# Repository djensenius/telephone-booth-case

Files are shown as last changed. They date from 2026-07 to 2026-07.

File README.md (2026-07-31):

# Telephone Booth Case

A parametric, 3D-printable enclosure for the [Telephone-Booth](https://github.com/djensenius/Telephone-Booth)
art project. It is a two-bay, screw-down (M3 corner-post) case that houses:

- **Back bay** — Raspberry Pi 4B + 52Pi GPIO Screw Terminal HAT, with a Noctua
  NF-A4x20 fan mounted on the lid.
- **Front bay** — GL.iNet MUDI 7 (GL-E5800) travel router, lying flat screen-up in
  a cradle so the screen shows through the lid window. The cradle rests on tapered
  support pillars that reduce print stringing.

Internal wiring runs between the bays through the central divider, which is left
open on the router's left end so the router's ethernet door can swing open and the
power cable can reach the Pi. Power path: external USB-C inlet → router power in;
the router's USB-out feeds the Pi via a right-angle USB dongle (the reason the
router bay has extra room on that end). Two panel RJ45 keystones wire to the 52Pi
HAT (GPIO).

Current embossed versions: base **v.0.7**, lid **v.0.7.1**

## Components

Parts the case is designed around (official product pages where available, Amazon
otherwise). Panel-cutout dimensions are matched by measurement to the specific
parts linked below — swapping a part may require adjusting the model.

| Component | Where it goes | Cutout | Link |
| --- | --- | --- | --- |
| Raspberry Pi 4 Model B | Back bay | 58 × 49 mm hole pattern | [raspberrypi.com](https://www.raspberrypi.com/products/raspberry-pi-4-model-b/) |
| 52Pi GPIO Screw Terminal HAT (EP-01129) | On the Pi | — | [52pi.com](https://52pi.com/products/52pi-gpio-screw-terminal-hat-for-raspberry-pi) |
| GL.iNet MUDI 7 (GL-E5800) 5G travel router | Front bay | cradle | [gl-inet.com](https://www.gl-inet.com/products/gl-e5800/) |
| Noctua NF-A4x20 40 mm fan | Lid | ⌀37 mm grille, 32 mm screws | [noctua.at](https://noctua.at/en/nf-a4x20-flx) |
| Round USB 3.0 panel-mount bulkhead, 86-type (×2) | Back wall (→ Pi USB-A) | ⌀22.6 mm round | [Amazon.ca](https://www.amazon.ca/dp/B0F2MW7XXZ) |
| USB-C 3.1 panel-mount coupler | Router-bay right wall (power inlet) | 13 × 8 mm, 23.5 mm screws | [Amazon.ca](https://www.amazon.ca/dp/B0GF22WM9T) |
| HDMI female → micro-HDMI screw-fixing panel-mount bulkhead | Right wall (→ Pi micro-HDMI) | ⌀23 mm round, M22×1.5 nut | [Amazon.ca](https://www.amazon.ca/dp/B0BRFS28JM) |
| RJ45 CAT6 keystone panel-mount (×2, GPIO) | Left wall | 16.5 × 13.1 mm, 24.5 mm screws | [Amazon.ca](https://www.amazon.ca/dp/B071FNHVXN) |
| Rugged metal RGB pushbutton, 16 mm (Pi power) | Right wall | ⌀16 mm round | [adafruit.com](https://www.adafruit.com/product/3350) |
| Right-angle USB-A → USB-A cable, 30 cm | Router USB-out → Pi power | — (internal) | — |

Fasteners: M2.5 screws for the Pi standoffs (driven up from the underside); the
Noctua fan ships with its own self-tapping screws.

## Parts (printed)

| File | Part | Description |
| --- | --- | --- |
| [`telephone-booth-case.scad`](telephone-booth-case.scad) | Source | Parametric OpenSCAD model (all dimensions live here) |
| [`base.stl`](base.stl) | Base | Two-bay body with standoffs, cradle + tapered supports, panel cutouts and vents |
| [`lid.stl`](lid.stl) | Lid | Snap-fit lid with fan grille and router screen window |

Outer size: **250 × 250 × 73.2 mm** (base 70.8 mm + 2.4 mm lid; lid screw posts
included). The Pi-bay panel cutouts (USB, HDMI, power button, both RJ45 keystones)
are centred on the assembled box height, and the USB audio adapter cradle sits
under the HDMI bulkhead. Both parts are embossed with the version,
author (David Jensenius) and contact (david@jensenius.com).

## Previews

| Preview | View |
| --- | --- |
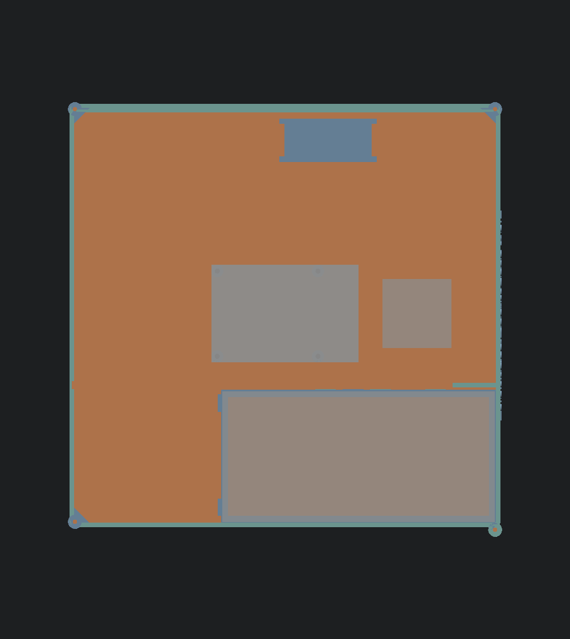
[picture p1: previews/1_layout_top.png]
Top layout
|  | Top-down layout with router + Pi ghosts |
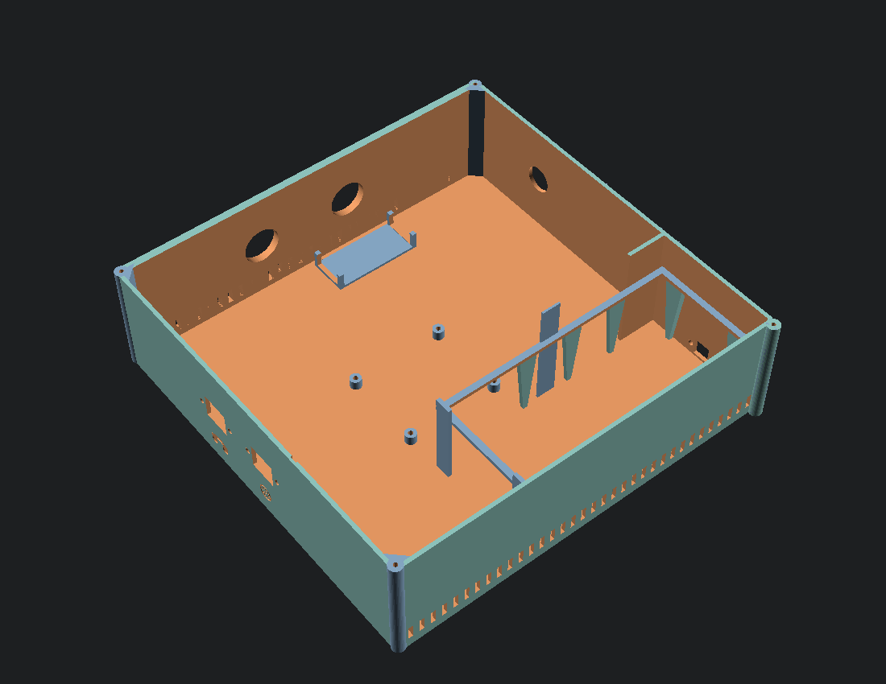
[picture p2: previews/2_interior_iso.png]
Interior
|  | Interior, both bays |
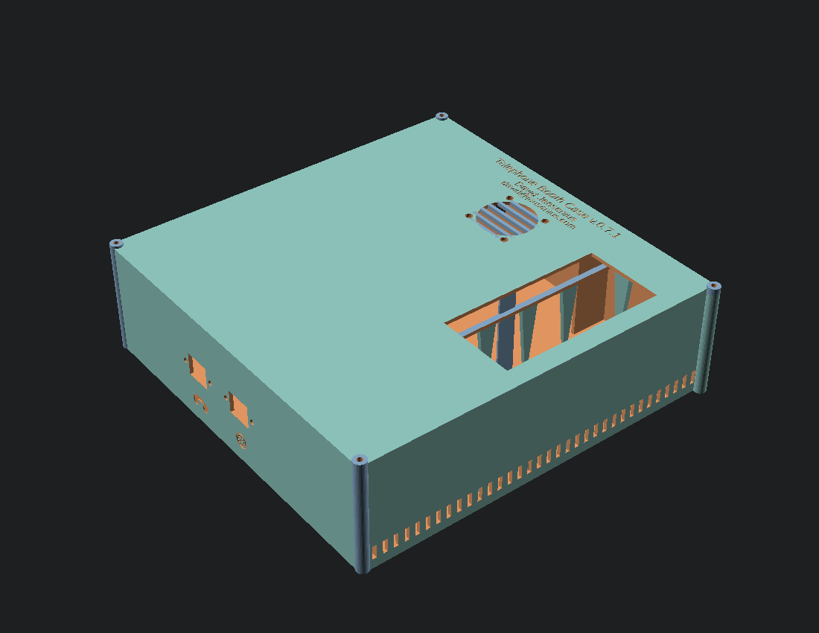
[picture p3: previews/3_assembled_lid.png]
Assembled lid
|  | Assembled — fan grille + screen window |
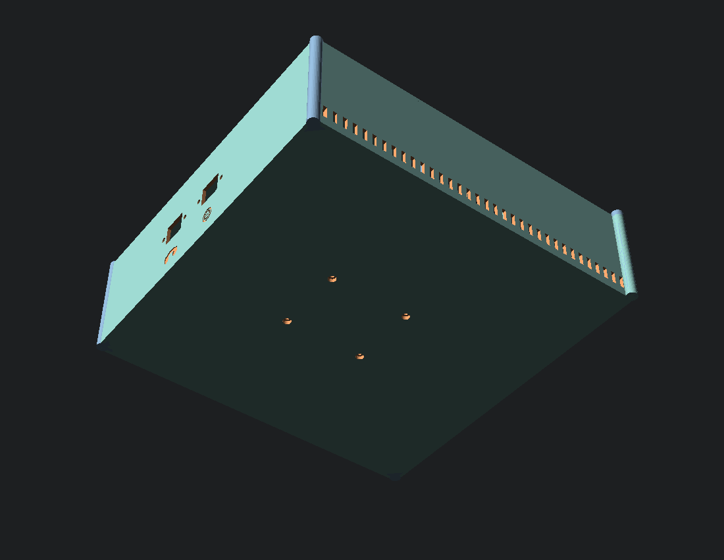
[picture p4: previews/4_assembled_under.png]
Underside
|  | Assembled underside |
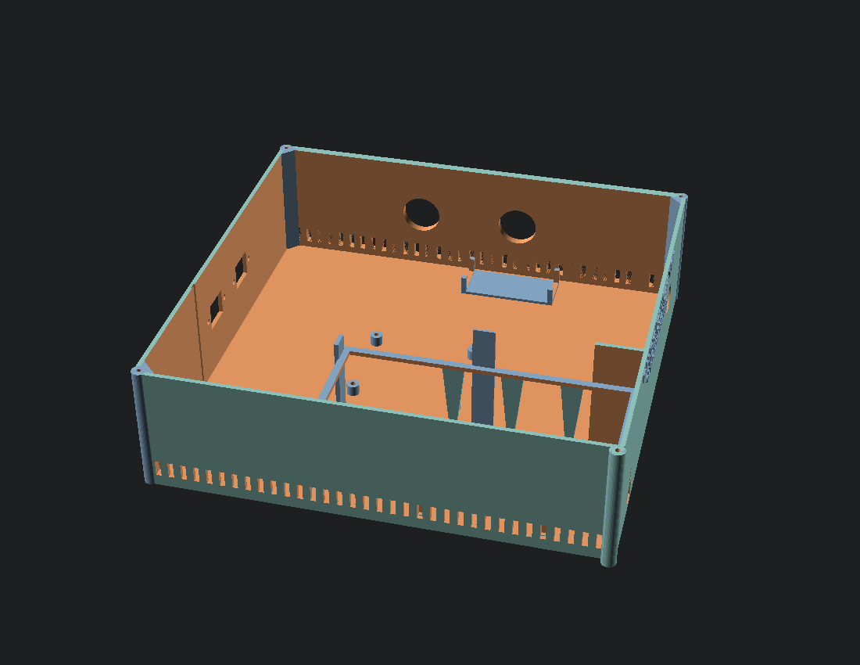
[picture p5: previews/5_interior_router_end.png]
Interior router end
|  | Interior from the router (USB-C) end — cradle supports |
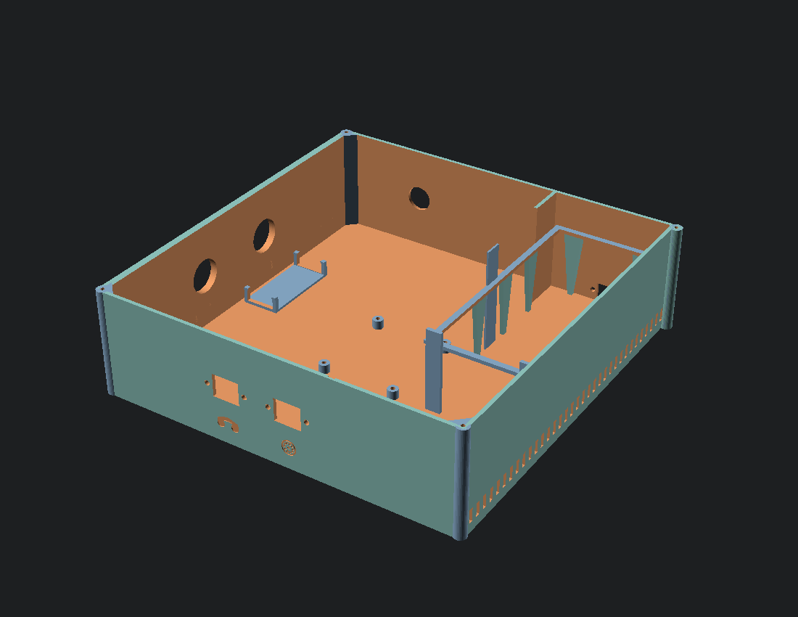
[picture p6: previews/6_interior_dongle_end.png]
Interior dongle end
|  | Interior from the dongle end — divider opened for cabling |
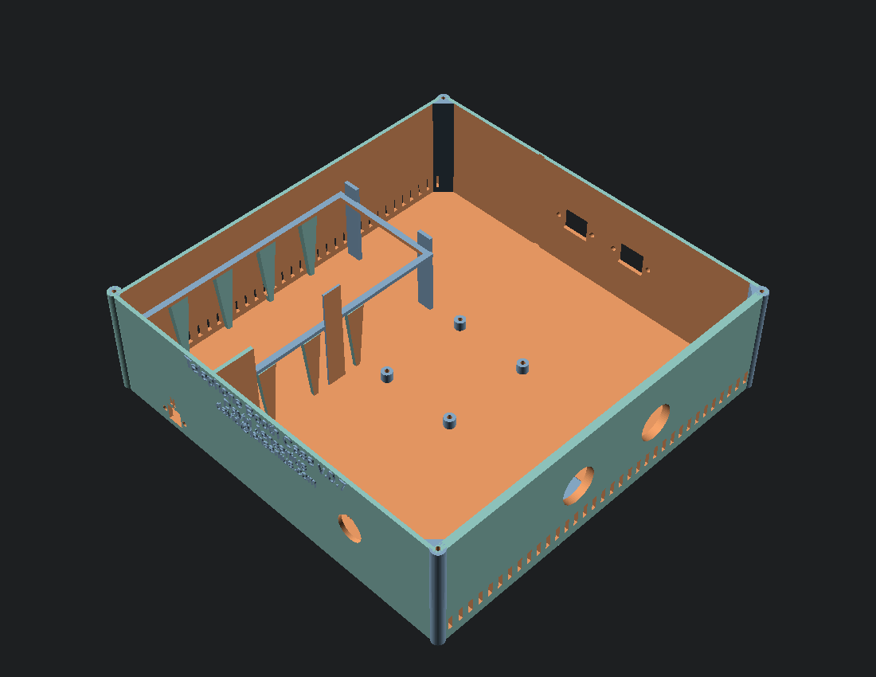
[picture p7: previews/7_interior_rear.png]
Interior rear
|  | Interior from the rear — cradle supports + left stops |
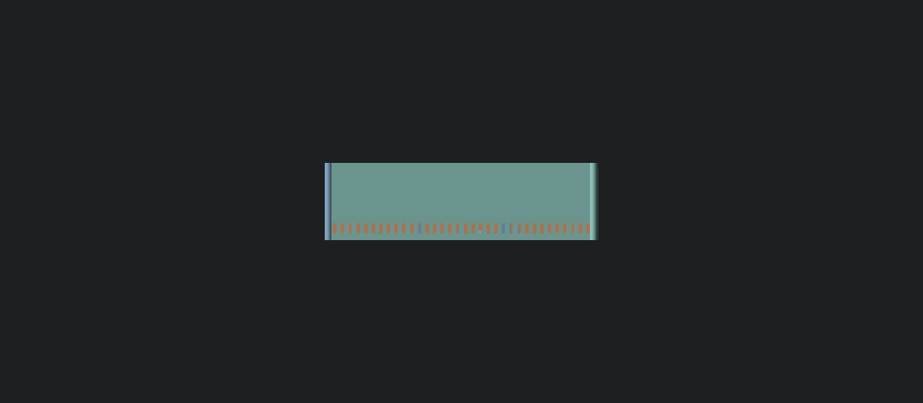
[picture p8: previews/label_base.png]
Base label
|  | Embossed label on the base front wall |
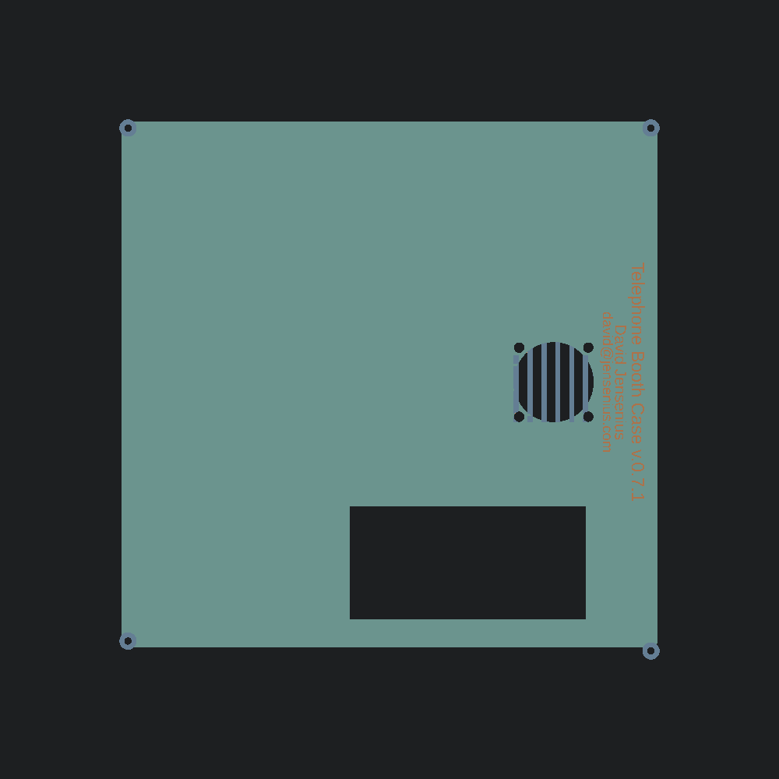
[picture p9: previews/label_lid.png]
Lid label
|  | Embossed label on the lid top |

## Printing / rendering

Requires [OpenSCAD](https://openscad.org/).

```sh
openscad -D 'part="base"' -o base.stl telephone-booth-case.scad
openscad -D 'part="lid"'  -o lid.stl  telephone-booth-case.scad
```

Use `-D 'part="check"'` for a translucent fit check with router and Pi ghosts.

## Versioning

The version is defined once, in the `label` parameter at the top of
`telephone-booth-case.scad`, embossed on both parts, and mirrored by the git tag
(embossed `v.0.1` ⇔ tag `v0.1`). See [`.github/copilot-instructions.md`](.github/copilot-instructions.md)
for the bump workflow.

## Related repositories

- [Telephone-Booth](https://github.com/djensenius/Telephone-Booth) — main project
- [Telephone-Booth-Operator](https://github.com/djensenius/Telephone-Booth-Operator)
- [Telephone-Booth-Operator-Mobile](https://github.com/djensenius/Telephone-Booth-Operator-Mobile)

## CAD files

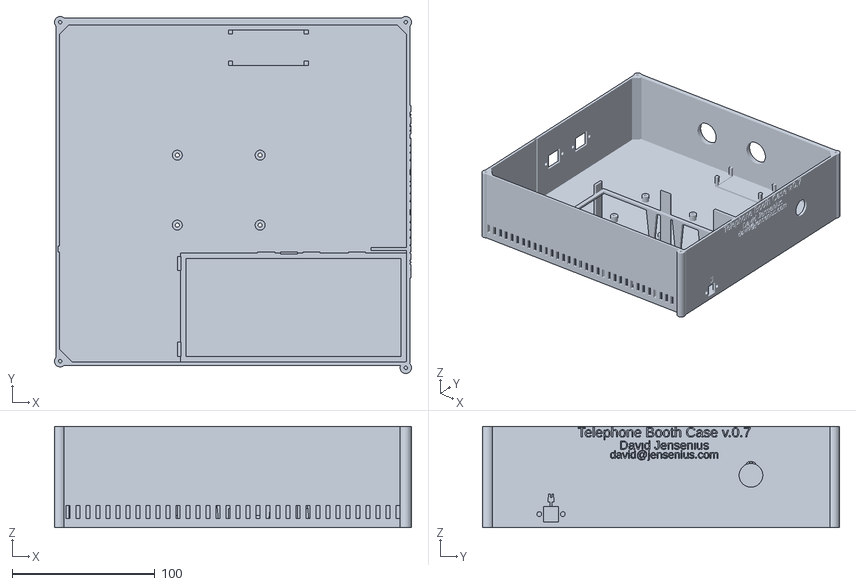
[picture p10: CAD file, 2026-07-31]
base.stl
250.0 x 250.0 x 70.8

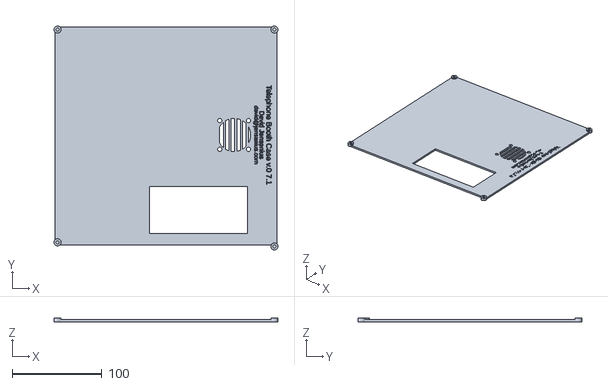
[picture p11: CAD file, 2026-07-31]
lid.stl
250.0 x 250.0 x 4.00

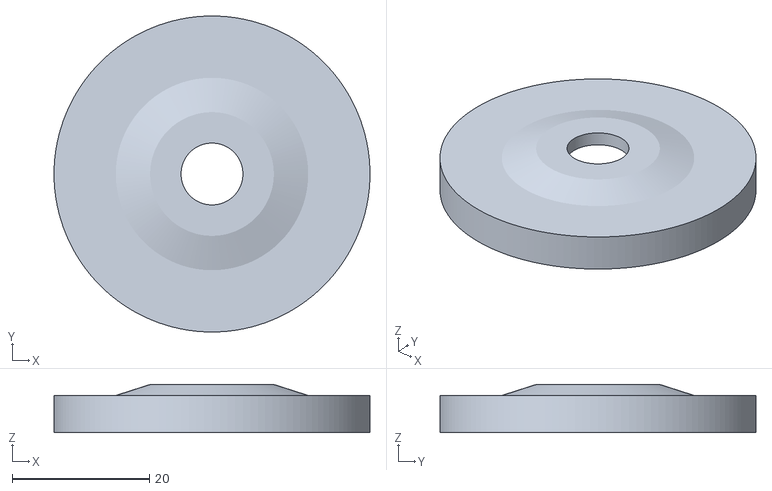
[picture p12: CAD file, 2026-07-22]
microphone-mount.stl
46.0 x 46.0 x 7.00

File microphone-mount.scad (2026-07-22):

// ============================================================================
// Telephone-Booth - microphone mount
//   A round disc that drops into the mouthpiece of an NE 233 handset in place
//   of the original built-in carbon microphone. It carries a small electret
//   condenser capsule, glued into the centre through-hole.
//
//   Profile (revolved, Z up, disc rests on the receiver at Z = 0):
//     * 46 mm outer diameter.
//     * A flat outer rim (the outer ~9 mm from the edge) that sits ON the
//       receiver, 5.4 mm thick.
//     * From ~9 mm in from the edge the body thickens toward the centre, up to
//       7 mm, forming a raised central boss.
//     * The underside recesses in the centre (a wide, deep dip) so the electret
//       capsule sits nestled below the rest face. The dip bottoms out on a flat
//       ledge so the capsule seats squarely.
//     * A 9 mm round through-hole at the centre holds the capsule (glued in).
//
// Render:
//   openscad -o microphone-mount.stl microphone-mount.scad
//   openscad -D section=true ... microphone-mount.scad   (half-section preview)
// ============================================================================

$fn = 128;

/* [Overall] */
disc_d      = 46;    // outer diameter
rim_th      = 5.4;   // thickness of the flat rim that rests on the receiver
boss_th     = 7;     // thickness at the raised central boss
rim_flat_w  = 9;     // width of the flat rim (from the edge inward) before it
                     // starts thickening toward the centre
boss_top_d  = 18;    // flat-top diameter of the boss (shoulder ramps up to here)

/* [Microphone dip - underside] */
mic_hole_d  = 9;     // centre through-hole - electret capsule glued in here
dip_open_d  = 28;    // diameter where the dip opens on the bottom face
dip_depth   = 5.0;   // how deep the dip sinks in from the bottom face
seat_d      = 13;    // flat ledge diameter at the top of the dip; the capsule
                     // seats against the annulus between here and the hole

/* [Preview] */
section     = false; // set true to render a half-section (dev preview only)

/* [Fit] */
eps = 0.01;

// ---------------------------------------------------------------------------

module microphone_mount() {
    r_out   = disc_d / 2;
    r_flat  = r_out - rim_flat_w;          // where the rim ends / boss begins
    r_hole  = mic_hole_d / 2;
    r_top   = boss_top_d / 2;
    r_open  = dip_open_d / 2;
    r_seat  = seat_d / 2;

    difference() {
        // Solid body of revolution: flat rim that ramps up to a taller boss.
        rotate_extrude()
            polygon(points = [
                [0,       0],
                [r_out,   0],
                [r_out,   rim_th],
                [r_flat,  rim_th],
                [r_top,   boss_th],   // top of the boss shoulder
                [0,       boss_th],
            ]);

        // Underside dip: a wide, deep recess funnelling up from the bottom face
        // to a flat ledge, so the mic drops in and seats squarely.
        translate([0, 0, -eps])
            cylinder(h = dip_depth + eps, r1 = r_open, r2 = r_seat);

        // Centre through-hole for the electret capsule.
        translate([0, 0, -eps])
            cylinder(h = boss_th + 2 * eps, r = r_hole);
    }
}

if (section)
    difference() {
        microphone_mount();
        translate([-50, 0, -5]) cube([100, 50, 30]);
    }
else
    microphone_mount();

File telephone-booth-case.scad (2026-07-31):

// ============================================================================
// Telephone-Booth enclosure - TWO-BAY design
//   Front bay : GL.iNet MUDI 7 (GL-E5800) router, 157 x 75 x 22.8 mm,
//               lying flat SCREEN UP, resting in a cradle, removable.
//   Back  bay : Raspberry Pi 4B + 52Pi GPIO Screw Terminal HAT, fan on lid.
//
// Router body size confirmed from the Mudi 7 wall-mount bracket STLs
// (75 mm wide, 22.8 mm thick) + GL.iNet spec (157 mm long).
//
// Internal wiring path (why the divider has a big passage + slack room):
//   External USB-C inlet  ->  router power-in
//   router PD output      ->  Pi power
//   router Ethernet       ->  Pi Ethernet
//   Two panel RJ45 (GPIO) ->  52Pi screw-terminal HAT
//
// VERIFY-before-final items (no reliable drawing): screen window size/pos,
// power-button position, USB-C / HDMI / RJ45 flange cutouts.
//
// Render:  openscad -D 'part="base"' -o base.stl telephone-booth-case.scad
//          openscad -D 'part="lid"'  -o lid.stl  telephone-booth-case.scad
//          openscad -D 'part="test"' -o test.stl telephone-booth-case.scad  (RJ45 fit coupon)
//          openscad -D 'part="test-usbc"' -o test-usbc.stl telephone-booth-case.scad  (USB-C fit coupon)
// ============================================================================

/* [What to render] */
part = "both";      // "base" | "lid" | "both" | "check" | "test" | "test-usbc"
$fn = 64;

/* [Shell] */
wall     = 2.4;
floor_th = 2.4;
roof_th  = 2.4;

/* [Raspberry Pi 4B] */
board_x    = 85;    // along X
board_y    = 56;    // along Y
board_th   = 1.4;
standoff_h = 6;     // lift PCB off floor
stack_h    = 28;    // PCB top -> top of 52Pi HAT + screw terminals (verified clearance)
roof_gap   = 33;    // stack top -> roof: sized so a 20 mm Noctua NF-A4x20 can hang
                    // UNDER the lid over the Pi bay with ~3 mm clearance to the HAT.
                    // v0.6: +10 mm (was 23) to make the whole box 10 mm taller -
                    // extra headroom above the Pi stack and below the router.
hole_dx    = 58;    // Pi mounting-hole rectangle (verified)
hole_dy    = 49;
hole_inset = 3.5;
post_od    = 7.0;
post_id    = 2.9;   // M2.5 clearance (screws driven up from underside)
cbore_d    = 5.6;
cbore_h    = 2.6;

/* [GL.iNet MUDI 7 router] */
rt_len = 157;       // along X
rt_wid = 75;        // along Y
rt_thk = 22.8;      // Z
rt_clr = 0.75;      // fit clearance around the body (snug: walls hug the router)
case_clr = 1.5;     // clearance the OUTER footprint is sized for (FIXED) - the box
                    // stays this size no matter how snug rt_clr makes the pocket;
                    // reclaimed space becomes dongle clearance + rear cable room
ledge_w = 4;        // cradle ledge that the router rests on
ledge_t = 2.4;      // ledge thickness
dongle_gap = 10.5;  // base clearance at the router's dongle (LEFT) end; the snug
                    // pocket adds any reclaimed width on top of this

/* [Cradle supports] */
sup_top_w = 12;     // support cap length along the rim (meets the ledge)
sup_foot  = 3;      // tapered support foot at the floor (less bridging -> less stringing)

/* [Bay layout] */
// v0.6: box enlarged to ~fill the Bambu P2S bed (256x256 max print). The router
// (modem) bay is UNCHANGED - it stays pinned to the front + right walls, so its
// placement is identical to v0.5. All the extra room lands on the Pi side: the
// width grows (Pi is centred, so it gains clearance on both sides) and pi_back
// grows (deeper rear cable zone behind the Pi, where the power lead enters).
// Lid screw-post geometry (defined here, ahead of [Bay layout], because the
// target-footprint math below needs it; used again in the corner-post section).
post_r = 4.0;         // corner post radius (external boss merged into the corner)
pin    = 3.0;         // inboard offset for the three roomy corners
box_x_target = 250;   // desired TRUE outer width  (X), lid posts INCLUDED
box_y_target = 250;   // desired TRUE outer depth  (Y), lid posts INCLUDED
// The M3 lid screw posts bulge past the nominal shell: ~ (post_r - pin) on the
// three inboard corners, and the front-right post (biased forward, clear of the
// router) sticks out further. Bake those overhangs in so box_*_target is the
// real printed footprint that must fit the bed - not the nominal shell size.
lid_bulge_side = post_r - pin;              // outward bulge, inboard corners (~1)
lid_bulge_fr   = post_r + (post_r - wall);  // forward stick of the front-right post (~5.6)
pi_front  = 12;     // board gap toward the divider
pocket_x  = rt_len + 2*rt_clr;         // snug router pocket X (walls hug the body)
pocket_y  = rt_wid + 2*rt_clr;         // snug router pocket Y
router_bay_x = rt_len + 2*case_clr;    // front-bay footprint X (fixed via case_clr)
router_bay_y = rt_wid + 2*case_clr;    // front-bay footprint Y (fixed via case_clr)
// Nominal shell size, backed off so the post bulges land ON the target footprint.
OUTX_target = box_x_target - 2*lid_bulge_side;
OUTY_target = box_y_target - lid_bulge_side - lid_bulge_fr;
IX        = max(router_bay_x + dongle_gap, board_x + 40, OUTX_target - 2*wall);   // box width
// pi_back is derived so the OUTER depth hits OUTY_target; it is the rear cable
// zone behind the Pi, so growing the box deepens exactly that space.
pi_back   = OUTY_target - 2*wall - (wall + router_bay_y + wall) - (board_y + pi_front);
pi_bay_y  = board_y + pi_front + pi_back;  // Pi bay depth

inner_h = standoff_h + board_th + stack_h + roof_gap;   // cavity height
base_h  = floor_th + inner_h;
cradle_z = inner_h - rt_thk;            // ledge rest height above floor

/* [Screw-down lid] - 4x M3 into external corner posts (secure, and no snap-fit
   parts to jam; the packed interior leaves no room for internal front posts).
   NB: post_r is defined earlier (Bay layout) - the footprint math needs it. */
lid_m3_clr  = 3.4;   // M3 clearance hole in the lid ear
m3_pilot    = 2.5;   // pilot hole in the base post for an M3 self-tapping screw
pilot_depth = 16;    // how deep the pilot bores down from the top of the post
ear_h       = 4.0;   // lid ear thickness (a low boss so the screw head seats well)

/* [Fan - Noctua NF-A4x20] */
fan_hole_dx = 32;
fan_screw   = 4.8;  // clearance for supplied self-tapping screws (opened up for fit)
fan_bore    = 37;
grille_bar  = 2.4;
grille_gap  = 4.0;

/* [Router screen window] - a large window over the router's top face. Each gap is
   measured from the OUTER case edge to where the opening starts. The opening runs
   ~133mm along X (33 + opening + 9.8 = OUTX) and 55mm along Y (from the left gap). */
screen_gap_front = 33;    // gap from the FRONT (min-X) outer edge to the opening
screen_gap_back  = 33.04; // gap from the BACK (USB-C / max-X) outer edge - filled in
                          // 23.24mm more from the top so it frames the LCD, not the
                          // empty glass above it
screen_gap_left  = 13.0;  // gap from the LEFT (y=0 front) outer edge - brought in 2.5mm
                          // from the right (front-wall) side to even the margin
screen_h         = 52.5;  // opening size along Y (Pi-side edge held fixed, where the
                          // modem sits flush)

/* [Ventilation] */
vent_slot_w = 3;
vent_slot_h = 9;
vent_gap    = 4;

/* [Panel round holes] */
usb_hole_d  = 22.6;  // 86-type threaded USB bulkhead
hdmi_hole_d = 23.0;  // screw-fixing HDMI bulkhead, M22x1.5 nut (cut Ø23) - Amazon B0BRFS28JM
btn_hole_d  = 16.6;  // 16 mm rugged metal RGB pushbutton (Adafruit 3350) - opened up for fit

/* [USB audio adapter cradle - US205] */
// Holds the US205 USB stereo sound adapter (drives the phone handset audio) in
// the Pi bay's rear cable zone so it can't rattle loose. Body size ESTIMATED
// from IMG_2489 scaled against the Pi board (~25.7 px/mm) - VERIFY with calipers.
aud_len    = 56;    // adapter body length along X
aud_wid    = 20;    // adapter body width  along Y (incl. a little clearance)
aud_slot_d = 9;     // how deep the body seats into the cradle ribs
aud_floor  = 2;     // material below the body
aud_wall   = 2.4;   // cradle side-wall thickness
aud_rib    = 3;     // rib thickness along X
aud_lip    = 0.6;   // inward retention nub at each rib's mouth (light snap)
// v0.7: aud_x0 (cradle left edge) is derived below - the cradle is now centred
// under the HDMI bulkhead instead of the USB one.
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

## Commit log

2026-07-19 Initial commit: two-bay Telephone Booth case v0.1
    [base.stl, lid.stl, telephone-booth-case.scad]
2026-07-20 v0.2: router cradle supports, dongle bay, opened divider, deeper Pi bay, round HDMI, power button, author emboss
    Router side:
    - Tapered support pillars under the router cradle to reduce print stringing
    - Add 10.5 mm dongle gap on the router's left end + corner retaining stops
    - Lower USB-C inlet to 7 mm, screws 23.5 mm apart; remove power-button hole
    - Open the divider on the left for the ethernet door + dongle power cable
    Pi side:
    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
    [telephone-booth-case.scad]
2026-07-20 v0.3: tighten router fit (rt_clr 1.5->0.75) + mid-span vertical stabilizers
    - Halve the router pocket clearance so the pocket walls hug the GL.iNet MUDI 7
    and remove the extra play visible in the assembled fit photos.
    - Add straight vertical stabilizer columns at the router mid-span, between the
    2nd and 3rd cradle supports on the front and back rims, to keep the router
    seated and stop it sagging/rocking.
    - Re-render base.stl / lid.stl (both manifold, NoError) and all previews.
    [telephone-booth-case.scad]
2026-07-20 v0.3: fix box footprint, Pi-bay panel rework, USB audio cradle, engraved lid label
    - Decouple the outer box size from the router pocket. A new fixed case_clr
    reference pins OUTX/OUTY (175.3 x 220.6 mm) so tightening rt_clr (0.75 mm)
    hugs the router without shrinking the case. Reclaimed width now lands as
    dongle clearance (12 mm) on the router's left end; the router is pushed
    against the right wall. Reclaimed depth becomes rear cable room.
    - Back wall: drop one USB (that Pi port now drives the USB audio adapter
    internally) and relocate the HDMI bulkhead into its place -> two round
    bulkheads (USB 22.6, HDMI 21.5).
    - Ethernet keystone windows raised 13.1 -> 15 mm tall (printed too t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
    [telephone-booth-case.scad]
2026-07-20 Fix vent rows: straddle wall centreline so both long walls cut through
    The vent_row cube was placed on the inner face of the wall; the front
    (router) wall's row sat entirely in the interior gap and cut nothing,
    so that wall printed solid. Centre the cube in Y and place each row on
    its wall centreline so both rows penetrate. Re-rendered base.stl and
    previews.
    [telephone-booth-case.scad]
2026-07-20 Router stabilizers: full-height fins the router seats between
    The router bay is hollowed the full width to the lid, so the router was
    located in Y only by the thin ledge and had ~3 mm of play - it rocked/
    bounced. Replace the short mid-span stabilizer posts with two full-height
    (floor-to-lid) fins forming a slot: a front fin against the front wall and
    a back fin against the divider. The router rests between them (front face
    seats a touch further back so the front fin has real thickness), pinning
    it in Y and bracing the case floor-to-lid. Re-rendered base.stl and
    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
    [telephone-booth-case.scad]
2026-07-20 Move USB audio cradle to the back wall by the USB hole
    The cradle sat ~40 mm in front of the back wall (just behind the Pi
    board). Relocate it hard against the back wall - the wall carrying the
    USB bulkhead - so it matches where the US205 adapter actually rests in
    the assembly photos, with a 6 mm rear gap for the bulkhead barrels.
    Re-rendered base.stl and previews.
    [telephone-booth-case.scad]
2026-07-21 Add engraved port symbols and side preview views
    Engrave three port labels into the base exterior walls: a power icon above
    the USB-C router power inlet (right wall), a telephone-handset over the audio
    jack and a rotary-dial disc over the dial jack (left wall). The two 'RJ45'
    ports are for booth audio and the rotary dial, not ethernet, so they now
    carry telephone symbols instead.
    Add left/right wall ortho previews (label_ports_left/right) to render.sh so
    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
    [telephone-booth-case.scad]
2026-07-22 v0.4: screw-down lid, internal fan, corner mounts, panel & label rework
    Base/lid enclosure revision driven by the v0.3 physical print feedback.
    Structure & fit:
    - Screw-down lid on integral inboard M3 corner columns (+45 deg gussets on
    FL/BL/BR) replacing the fragile outboard snap posts.
    - Front-right column adds a chamfered buttress that welds it into the front +
    right walls (the router fills that corner so it must protrude slightly).
    - Single full-height router-brace wall on the back (divider) side; router seated
    snug to the front wall.
    - Taller bay for internal Noctua fan clearance over the Pi + HAT.
    Panel & ports:
    - Screen window 132.5 x 55 mm over the router bay (gaps 33/9.8 mm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
    [microphone-mount.scad, microphone-mount.stl, telephone-booth-case.scad]
2026-07-22 v0.5: modem window, corner screws, HDMI Ø23, USB-C dongle clearance, port icons
    - Shrink modem screen window: fill 23.24mm from top (LCD is top-aligned) and
    bring the front-wall (right) edge in 2.5mm; Pi-side edge held flush.
    - Fix corner lid-screw blind-hole bug: the roof was back-filling the ear holes,
    so the M3 clearance holes are now drilled through the full ear+roof stack.
    - HDMI bulkhead swapped to a screw-fixing adapter (Amazon B0BRFS28JM): hole
    Ø21.5 -> Ø23 for the M22x1.5 nut. README updated.
    - Clear the USB-C power-inlet pocket: spread the two right-side rim supports to
    g=0.2/0.82 so neither crowds the low right-angle dongle entering under the router.
    - Port icons: engra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
    [telephone-booth-case.scad]
2026-07-27 Bump to v0.6: correct RJ45 & USB-C panel-mount cutouts (#5)
    - RJ45 keystone: screw spacing 24.5 -> 25.75 mm (c-c), window 16.5 ->
    18 mm, screw holes 3.2 -> 3.4 mm (matched to USB-C).
    - USB-C inlet: screw spacing -> 16.5 mm (c-c), window 13x8 -> 10.5x11 mm,
    screw holes -> 3.4 mm.
    - Add min_web guard (check_panel_holes) so screw holes that would break
    into a port window fail the render instead of silently merging.
    - Add flat fit-test coupons: part="test" (RJ45) and part="test-usbc".
    - Re-render base/lid STLs and previews.
    [base.stl, lid.stl, telephone-booth-case.scad]
2026-07-27 v0.6: make box target the TRUE footprint (lid posts included) (#6)
    The 250 mm target was the nominal shell size, but the M3 lid screw posts
    bulge past it - the front-right post (biased forward, clear of the router)
    pushed the real Y extent to 256.6 mm, over the P2S 256 mm print limit.
    - box_x_target / box_y_target now mean the TRUE printed footprint. The
    post overhangs (lid_bulge_side, lid_bulge_fr) are subtracted to get the
    nominal shell (OUTX_target / OUTY_target), so 250 renders as a real
    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
    [base.stl, lid.stl, telephone-booth-case.scad]
2026-07-29 v0.7: audio cradle under HDMI, centred panel cutouts, one less cradle support
    - Move the USB audio adapter cradle from under the USB bulkhead to under the
    HDMI bulkhead (aud_x0 is now derived from the Pi board + hdmi_along_off).
    - Centre the USB, HDMI, power button and both RJ45 keystone cutouts on the
    assembled box height (panel_up = inner_h/2 = 34.2 mm above the floor).
    - Drop the divider-side cradle pillar nearest the network-hole end.
    - Bump the embossed version to v.0.7; re-render STLs and previews; refresh the
    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
    [base.stl, lid.stl, telephone-booth-case.scad]
2026-07-31 v0.7.1: move lid fan and label toward +X edge
    [lid.stl, telephone-booth-case.scad]
